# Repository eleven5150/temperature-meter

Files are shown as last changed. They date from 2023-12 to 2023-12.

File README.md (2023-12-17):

# temperature-meter

Устройство визуальной индикации температуры в помещении

# PCB

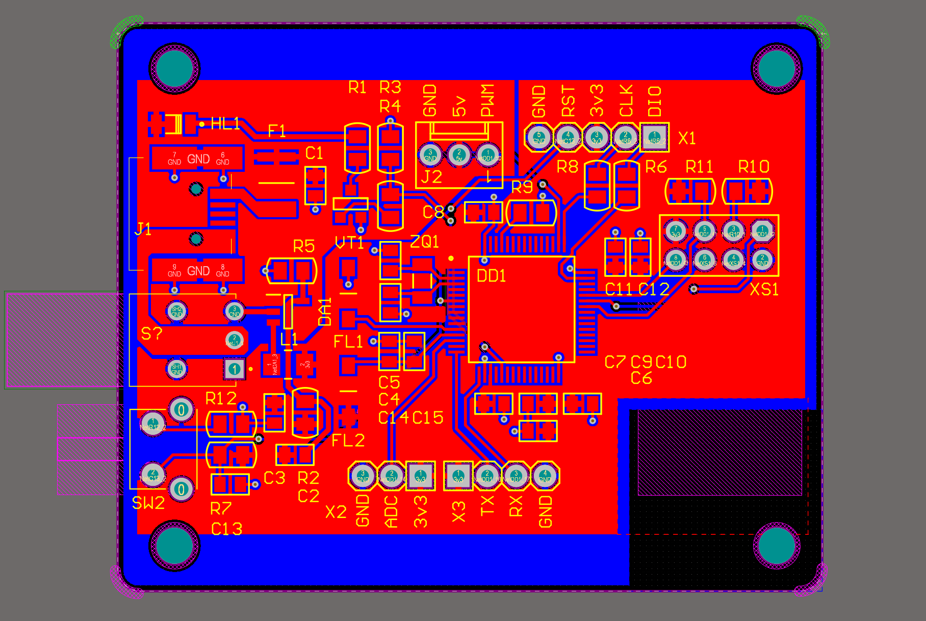
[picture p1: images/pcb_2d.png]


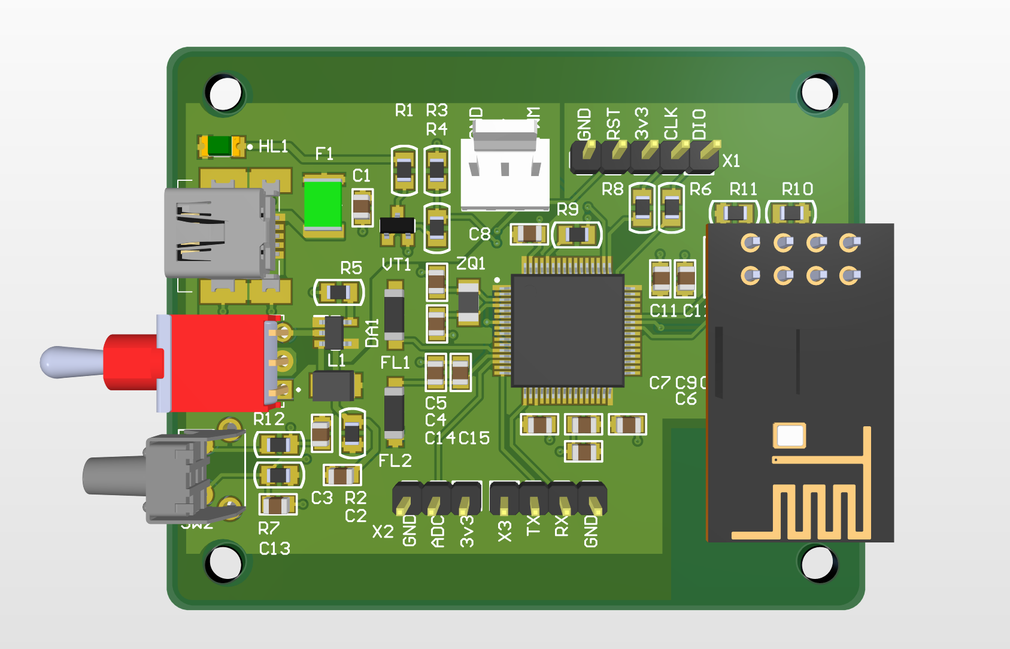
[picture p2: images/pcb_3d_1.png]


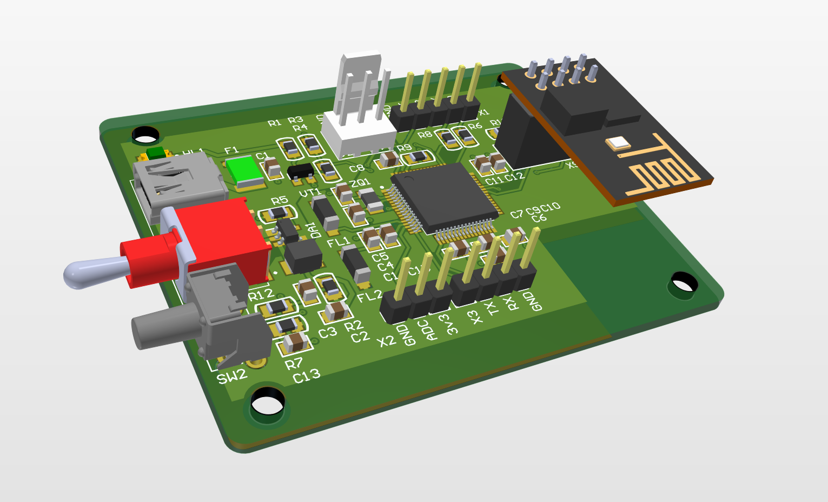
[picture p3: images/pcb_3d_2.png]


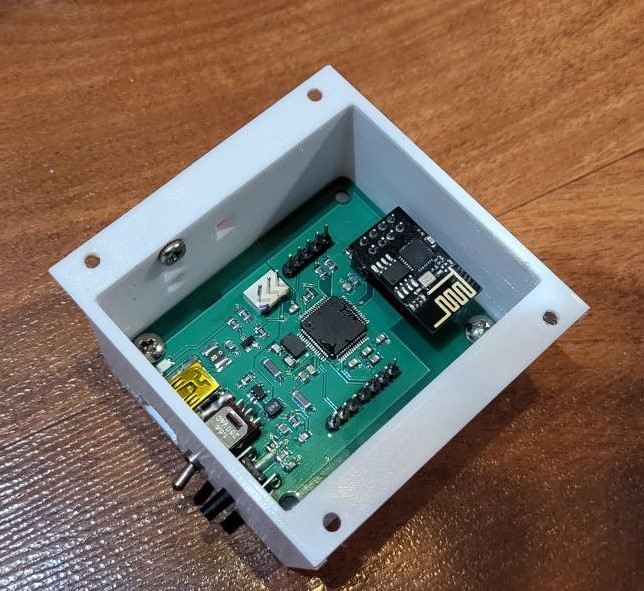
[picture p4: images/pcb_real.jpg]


# Case

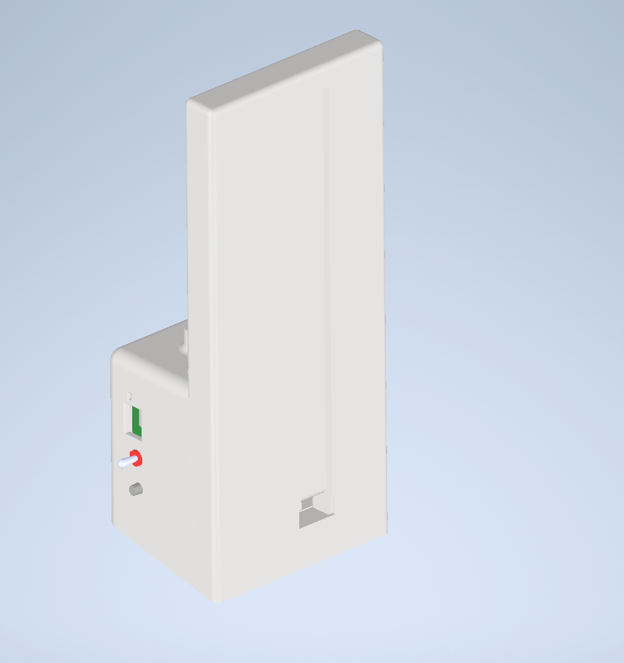
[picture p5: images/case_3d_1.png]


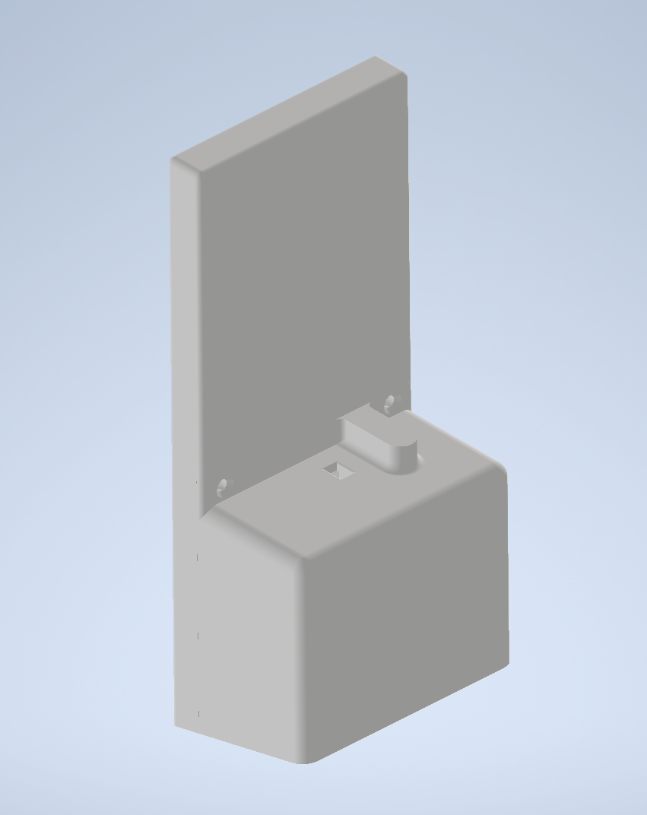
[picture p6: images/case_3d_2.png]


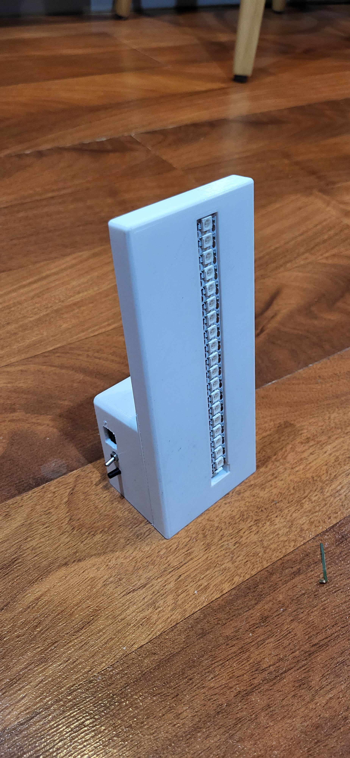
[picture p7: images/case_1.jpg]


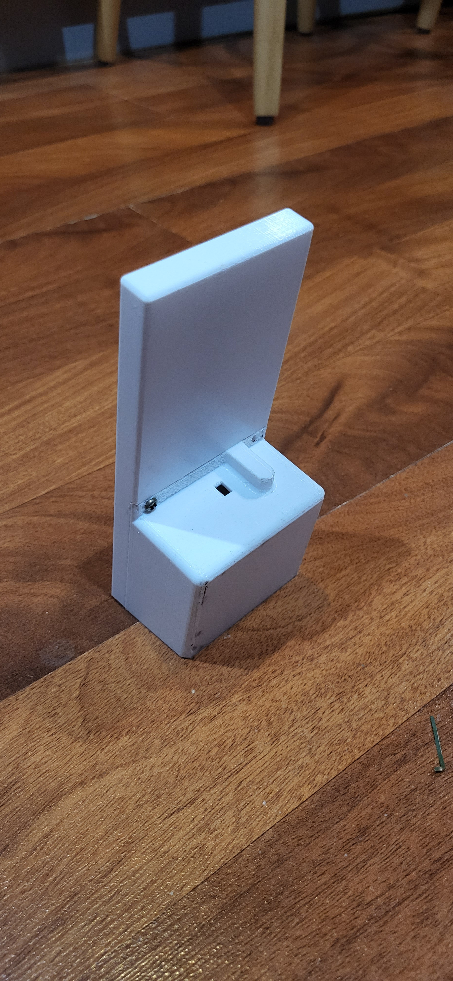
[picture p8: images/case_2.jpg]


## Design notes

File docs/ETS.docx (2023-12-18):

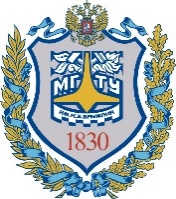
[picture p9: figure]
Gerb-BMSTU_01

| Министерство науки и высшего образования Российской Федерации Федеральное государственное бюджетное образовательное учреждение высшего образования «Московский государственный технический университет имени Н.Э. Баумана (национальный исследовательский университет)» (МГТУ им. Н.Э. Баумана)

ФАКУЛЬТЕТ «ИНФОРМАТИКА, ИСКУССТВЕННЫЙ ИНТЕЛЛЕКТ И СИСТЕМЫ УПРАВЛЕНИЯ» (ИУ)

КАФЕДРА «ПРОЕКТИРОВАНИЕ И ТЕХНОЛОГИЯ ПРОИЗВОДСТВА ЭА» (ИУ4)

РАСШИРЕННОЕ ТЕХНИЧЕСКОЕ ЗАДАНИЕ

на выполнение курсового проекта

на тему: «Устройство визуальной индикации температуры в помещении»

Студент ИУ4-31М _________________ Кутаев К.С.

(Группа) (Подпись, дата)

Руководитель _________________ Орлов А.О.

(Подпись, дата)

Москва, 2023

# 1.1 НАИМЕНОВАНИЕ, НАЗНАЧЕНИЕ И ОБЛАСТЬ ПРИМЕНЕНИЯ.

1.1.1 Наименование разрабатываемого изделия – «Устройство визуальной индикации температуры в помещении».

1.1.2 Изделие предназначено для визуальной индикации температуры в помещении на температурной шкале, а также в цифровом виде на пользовательской веб странице.

1.1.3 Применяется в домашних и офисных помещениях, где необходимо иметь возможность контролировать температуру как визуально, так и иметь ее значение в цифровом виде для передачи каким-либо системам, способным ее регулировать.

1.1.4 «Устройство визуальной индикации температуры в помещении» осуществляет соединение по беспроводной технологии Wi-Fi и является HTTP сервером для подключения к нему клиентских устройств и возможностью обмена данными по протоколу HTTP. На устройстве расположена светодиодная лента, которая осуществляет визуальную индикацию температуры в помещении на температурной шкале градусов Цельсия.

1.2 ОСНОВАНИЕ ДЛЯ РАЗРАБОТКИ.

1.2.1 Настоящее техническое задание разработано в соответствии с заданием на курсовой проект кафедры ИУ4 МГТУ им Н. Э. Баумана.

1.3 ЦЕЛЬ И НАЗНАЧЕНИЕ РАЗРАБОТКИ.

1.3.1 Цель разработки – создание «Устройства визуальной индикации температуры в помещении», для визуальной индикации температуры в помещении на температурной шкале, а также в цифровом виде на пользовательской веб странице.

1.3.2 «Устройство визуальной индикации температуры в помещении» должно иметь питание, достаточное для нормальный работы светодиодной ленты и работать в климатических условиях УХЛ 3.1.

# 1.4 ИСТОЧНИКИ РАЗРАБОТКИ.

1.4.1 Опыт, накопленный студентом в разработке устройств, использующих светодиоды в качестве индикации и опыт работы с АЦП.

1.4.2 Анализ источников информации об аналогах.

# 1.5 ПРИНЦИП ДЕЙСТВИЯ.

1.5.1 Для включения устройства необходимо подключить устройство к сети питания постоянного тока 5В по средствам USB кабеля USB Type-A на Mini-USB Type-B. После подачи питания на «Устройство визуальной индикации температуры в помещении» загорится светодиод, означающий правильную работу устройства.

Функционал режимов индикации и передачи данных по сети регулируются соответствующей версией внутреннего программного обеспечения УВИТП, в зависимости от назначения поставки, загружаемого непосредственно при выполнении заказа.

При передаче на Устройство запроса о получении значения температуры в помещении устройство выдает ответ в виде HTML файла с форматированными данными.

# 1.6 ОБЪЕКТ ОБРАБОТКИ.

1.6.1 Объект обработки – информация о температуре в помещении, где расположено УВИТП.

# 1.7 ТЕХНИЧЕСКИЕ ТРЕБОВАНИЯ.

## 1.7.1 Требования по составу изделия.

1.7.1.1 Устройство визуальной индикации температуры в помещении предназначено для визуальной индикации температуры в помещении на температурной шкале, а также в цифровом виде на пользовательской веб странице.

1.7.1.2 В состав каждого изделия должны входить:

- «Устройство визуальной индикации температуры в помещении», далее по тексту УВИТП, со средствами упаковки, обеспечивающими его транспортирование и хранение;

- принадлежности и эксплуатационная документация, необходимые для выполнения работ по обслуживанию УВИТП в условиях эксплуатации и хранения;

1.7.1.3 Комплект ПО, необходимого для эксплуатации УВИТП:

- тестирование (подготовка к работе);

- копирования данных (перенос данных в персональный компьютер);

- расшифровки данных (получение и передача информации, хранящейся на внутренней flash-памяти).

1.7.1.4 В состав устройства входят:

- МК STM32F103RDT6;

- кварцевый резонатор;

- 74 керамических конденсатора;

- импульсный регулятор питания;

- 61 светодиод;

- предохранитель;

- катушка индуктивности;

- 13 резисторов;

- рычаг переключатель;

- тактовая кнопка;

- транзистор;

- вилка штыревая;

- гнездо контактное.

1.7.1.5 Разрабатываемое устройство должно быть выполнено в виде одноплатной электронной ячейки на двухсторонней печатной плате, заключенной в прямоугольный пластмассовый корпус.

## 1.7.2 Требования по назначению.

1.7.2.1 УВИТП должно обеспечивать прием и передачу информации, хранящейся на внутренней flash-памяти;

1.7.2.2 Изделие должно обеспечивать:

- вывод графической информации о температуре в помещении;

- возможность ввода информации посредством протокола HTTP, с последующей передачей данных по беспроводной технологии Wi-Fi;

1.7.2.4 Погрешность определения значения температуры не должна превышать 1 с;

1.7.2.5 Электрическая прочность и сопротивление изоляции УВИТП – по ГОСТ Р 52931;

1.7.2.6 Напряжение питания – 5 В с погрешностью 0,5 В. Ток для питания УВИТП, обеспечиваемое ресурсом источника питания, - не менее 1 Ампера.

1.7.2.7 УВИТП должно сохранять работоспособность при температуре окружающей среды от -10 °C до 40 °C и относительной влажности воздуха 60% при температуре 25 °C.

1.7.2.8 Устройство должен сохранять работоспособность после его транспортирования и хранения при температуре (от минус 25 °C до 50 °C) в среде без агрессивных примесей (кислот, щелочей и др.).

1.7.2.9 Устройство должен сохранять работоспособность при воздействии на него вибрации на диапазоне частот от 10 до 100 Гц по ГОСТ 28203-89.

1.7.2.10 Устройство должен сохранять работоспособность при воздействии на него ударных нагрузок с ускорением до 10g длительностью до 15 мс и частотой от 40 до 80 1/мин. Вибрация в диапазоне частот от 10 до 100 Гц с ускорением до 1,5 g.

1.7.2.11 Масса Устройства - не более 0,5 кг.

1.7.2.12 Потребляемая мощность устройства не превышает 3 Вт.

1.7.2.13 Максимальный потребляемый ток – 3 А.

1.7.2.14 Технология беспроводной передачи данных – Wi-Fi.

1.7.2.15 Максимальное количество зажигаемых светодиодов на светодиодной ленте – 60 шт.

1.7.2.15 Заданный объём выпуска Nвып= 1000 шт./год.

1.7.2.16 IP адрес устройства выдается с использованием протокола DHCP при подключении к сети.

## 1.7.3 Требования к надежности.

1.7.3.1 Установленная вероятность безотказной работы УВИТП в течение наработки не менее 5000 часов должна быть не менее 0,95.

1.7.3.2 Средний срок службы УВИТП не менее 1,5 лет. Установленный срок службы - 1 год.

## 1.7.4 Требования к уровню унификации и стандартизации.

1.7.4.1 Требования к уровню унификации и стандартизации не предъявляются.

## 1.7.5 Требования безопасности и требования по охране природы.

1.7.5.1 УВИТП должен быть безопасными при использовании его пользователем, прочитавшим правилам эксплуатации устройства.

1.7.5.2 Блок питания и его компоненты должны быть правильно утилизированы.

1.7.5.3 В эксплуатационной документации на Устройство должны быть ссылки на общие требования безопасности в соответствии со следующими документами:

- ГОСТ 12.3.019 Испытания и измерения электрические. Общие требования безопасности;

- ГОСТ 12.2.003 Оборудование производственное. Общие требования безопасности;

- ГОСТ 12.3.020 Процессы перемещения грузов на предприятиях. Общие требования безопасности;

- ГОСТ 12.2.007.0 Изделия электротехнические. Общие требования безопасности;

- ГОСТ 12.1.004 Пожарная безопасность. Общие требования;

- ГОСТ 12.3.002 Процессы производственные. Общие требования безопасности;

1.7.5.4 Требования по охране природы не предъявляются, так как при изготовлении, эксплуатации, транспортировании, хранении, утилизации УВИТП отсутствуют вредные воздействия на элементы окружающей среды.

## 1.7.6 Требования к составным частям, сырью и исходным материалам.

## 1.7.6.1 Покупные изделия и материалы применяются без ограничений.

## 1.7.7 Условия эксплуатации, требования к техническому обслуживанию и ремонту.

1.7.7.1 УВИТП должно быть выполнено для климатической зоны УХЛ 3.1 по ГОСТ 15150.

1.7.7.2 УВИТП должно сохранять работоспособность при температуре среды от -10 °C до 40 °C и относительной влажности воздуха 60% при температуре 25 °C.

1.7.7.3 УВИТП должно сохранять работоспособность после его транспортирования и хранения при температуре от минус 25 °C до 50 °C в среде без агрессивных примесей.

1.7.7.4 Техническое обслуживание УВИТП должно обеспечиваться при проведении работ по их подготовке к обследованию объектов контроля, работ после проведения контроля и работ по подготовке к хранению.

1.7.7.5 Для увеличения достоверности информации, получаемой с установленных устройств ввода и вывода, допускается проведение периодической проверки и калибровки.

## 1.7.8 Требования к маркировке и упаковке.

1.7.8.1 Требования к маркировке не предъявляются.

## 1.7.9 Требования к транспортированию и хранению.

1.7.9.1 УВИТП должно выдерживать транспортирование в пассажирских салонах всех видов транспорта без ограничения расстояния перевозки.

# 1.8 ПОРЯДОК КОНТРОЛЯ И ПРИЕМКИ

1.8.1 Для приемки представляется один опытный образец платы печатной УВИТП, комплект эксплуатационных документов, комплект программного обеспечения, программа и методика приемных испытаний, согласованная в установленном порядке.

1.8.2 Конструкторская и технологическая документация должна быть разработана в соответствии с требованиями ГОСТ ЕСКД.

1.8.3 В комплекты эксплуатационных документов должны быть включены следующие документы:

– схема электрическая структурная УВИТП (Э1),

– схема электрическая принципиальная УВИТП (Э3),

– схема электрическая соединений УВИТП (Э4),

– перечень элементов электронной ячейки УВИТП (ПЭ),

– чертеж печатной платы УВИТП(ПП),

– сборочный чертеж электронной ячейки УВИТП(СБ),

– спецификация электронной ячейки УВИТП(СП),

– чертежи основания и крышки корпуса УВИТП,

– сборочный чертёж УВИТП,

– спецификация УВИТП(СП),

– алгоритм работы УВИТП,

– расчётно-пояснительная записка.

1.8.4 Приемные испытания УВИТП проводятся на образцах с искусственными или естественными дефектами, предоставляемыми заказчиком.

1.8.5 По результатам проведения испытаний, при необходимости проводится корректировка конструкторской документации.

1.8.6 Отдельные требования настоящего технического задания могут изменяться и дополняться по согласованию сторон в установленном порядке.

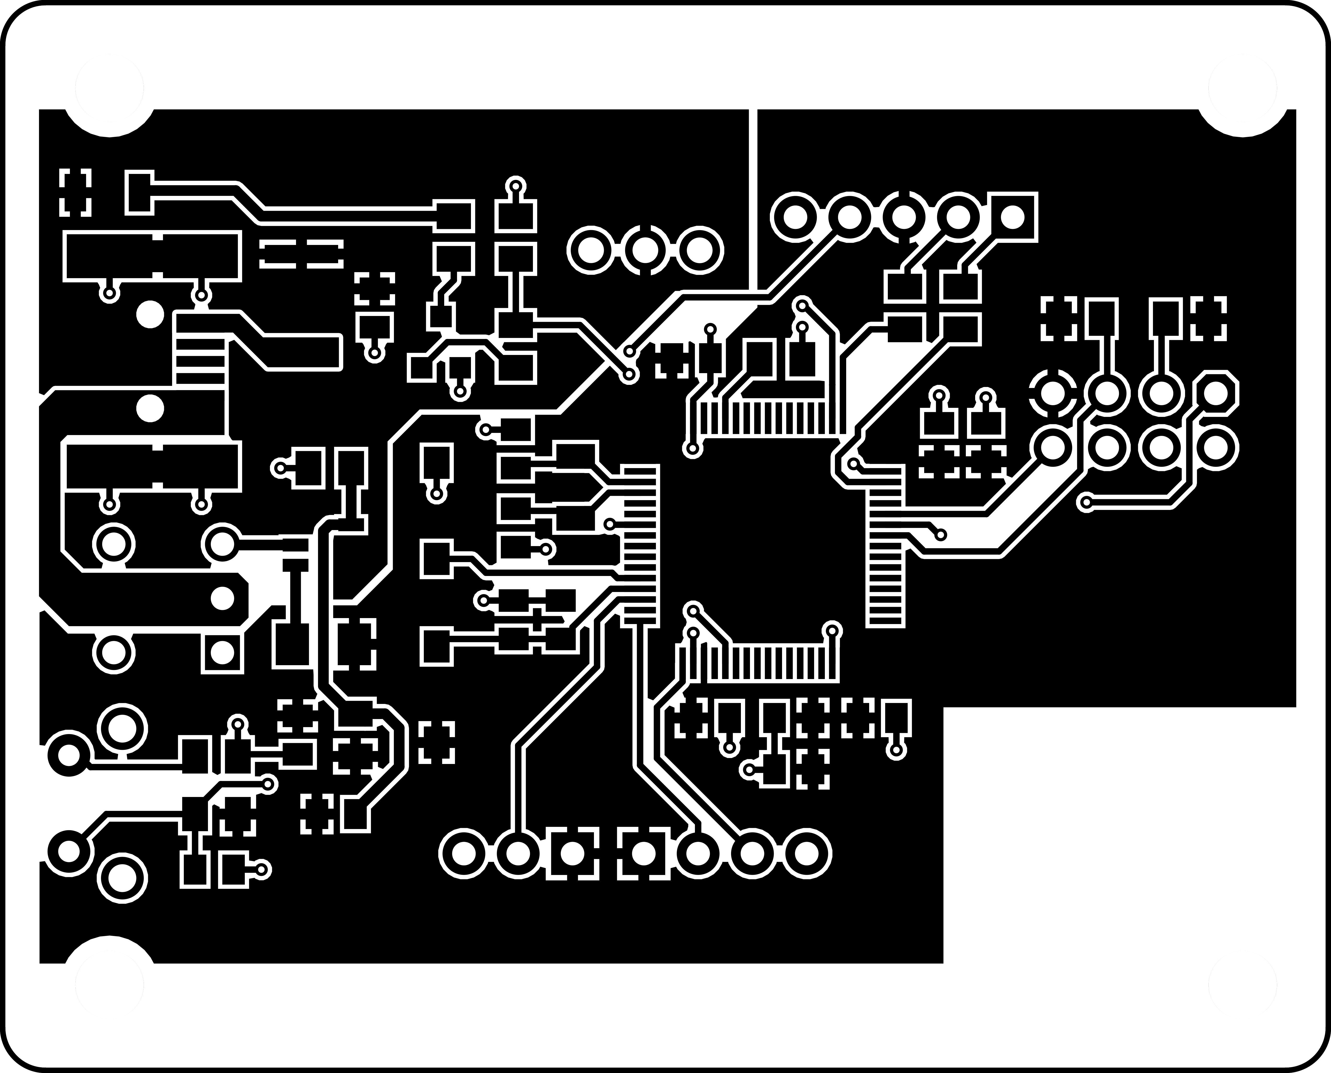
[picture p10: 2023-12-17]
docs/drawings/cell/src/pcb_src/top.png

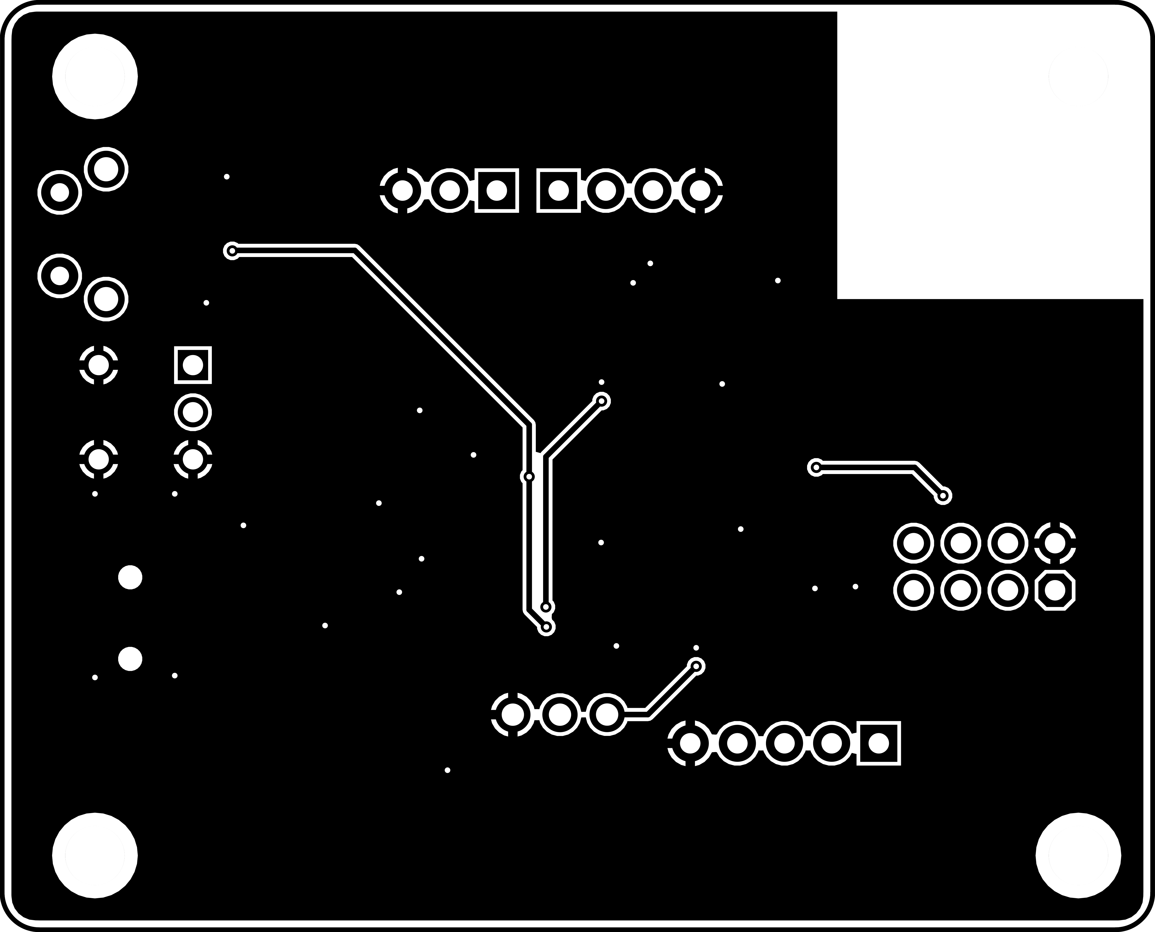
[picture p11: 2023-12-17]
docs/drawings/cell/src/pcb_src/bot.png

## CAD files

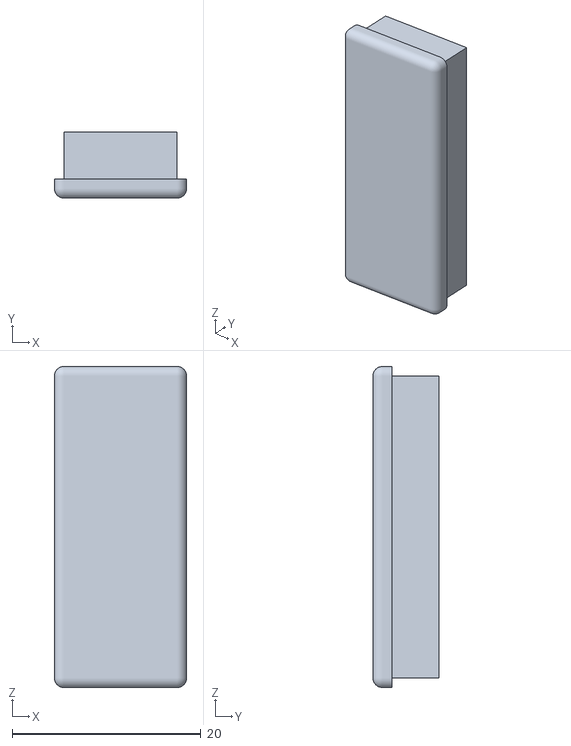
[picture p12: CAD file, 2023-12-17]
case/pcb/ST_FLASH.stl
14.0 x 7.00 x 34.0

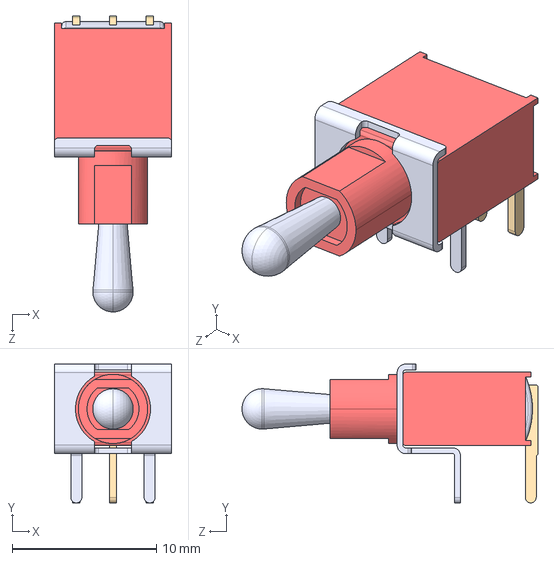
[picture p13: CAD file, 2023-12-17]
pcb/2AS1T2A1M6RES--3DModel-STEP-56544.STEP
8.13 x 9.62 x 20.5 mm

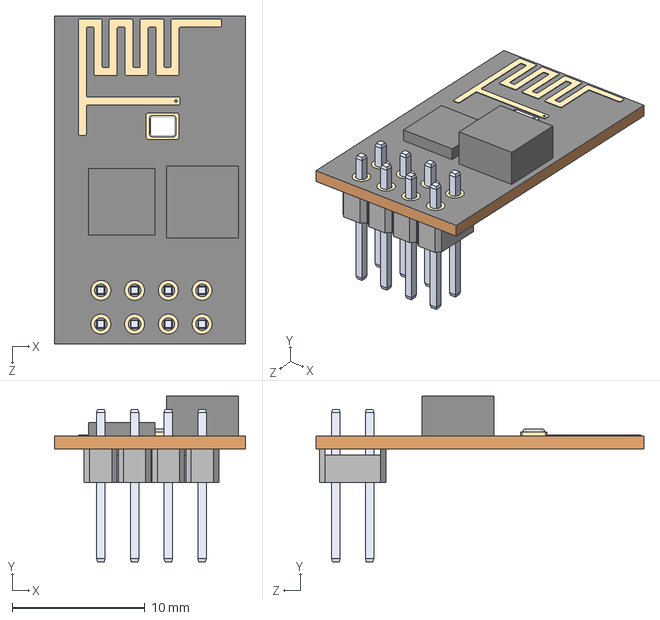
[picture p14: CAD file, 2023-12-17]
pcb/ESP-01.STEP
14.4 x 12.5 x 24.7 mm

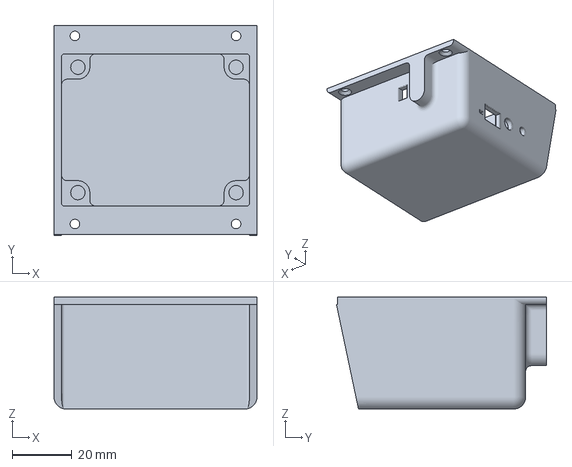
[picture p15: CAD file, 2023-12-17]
pcb/CE3PRO_Top.3mf
68.0 x 70.4 x 37.5 mm

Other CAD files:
docs/drawings/device/src/Assembly.dwg
docs/drawings/cell/src/Assembly.dwg
docs/drawings/cell/src/E3.dwg
docs/drawings/device/src/Case Cap.dwg
pcb/export_step/pcbPCB1_A.dwg
docs/drawings/cell/src/E4.dwg
docs/drawings/device/src/Case Base.dwg
pcb/export_step/pcbPCB1_I.dwg
docs/drawings/cell/src/BOM.dwg
docs/drawings/cell/src/E1.dwg
docs/drawings/device/src/Specs.dwg
docs/drawings/cell/src/PCB.dwg
docs/drawings/device/src/Research Result.dwg
docs/drawings/device/src/Algorithm.dwg
case/Base.ipt
case/Cap.ipt
case/Case-ASMB.iam
case/Temp_Module.ipt
case/pcb/7243460688.ipt
case/pcb/7243461008.iam
case/pcb/7243461088.ipt
case/pcb/7243462128.ipt
case/pcb/7243474768.iam
case/pcb/7403978528.iam
case/pcb/Board.iam
case/pcb/Body_1.ipt
case/pcb/Body_2.ipt
case/pcb/C1.iam
case/pcb/C10.iam
case/pcb/C11.iam
case/pcb/C12.iam
case/pcb/C13.iam
case/pcb/C14.iam
case/pcb/C15.iam
case/pcb/C2.iam
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

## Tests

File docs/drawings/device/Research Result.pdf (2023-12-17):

Пакет с цветовым кодом для светодиодной ленты . Способ передачи - ШИМ

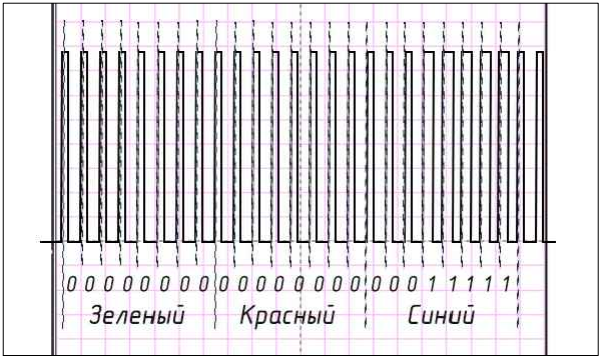
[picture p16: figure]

Теоретический график

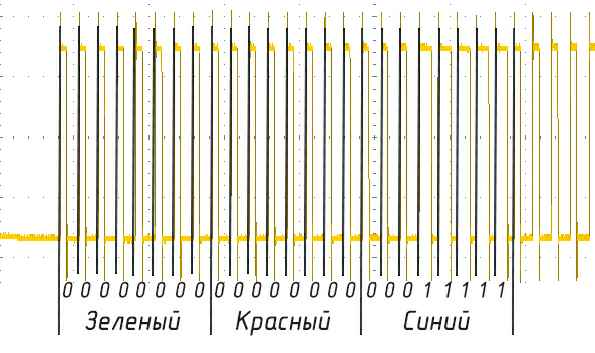
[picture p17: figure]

Практический график

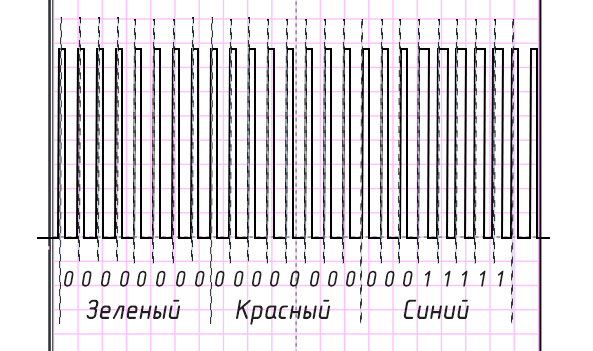
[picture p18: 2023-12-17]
docs/drawings/device/src/research_result_pictures/ledstripMod.jpg

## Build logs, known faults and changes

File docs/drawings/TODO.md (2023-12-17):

# Cell
- [x] E1
- [x] E3
- [x] BOM
- [x] E4
- [x] PCB
- [x] Assembly
- [x] Specs

# Device

- [x] Algorithm
- [x] Case Base
- [x] Case Cap
- [x] Case Assembly 
- [x] Device Specs
- [x] Research stand
- [x] Research result

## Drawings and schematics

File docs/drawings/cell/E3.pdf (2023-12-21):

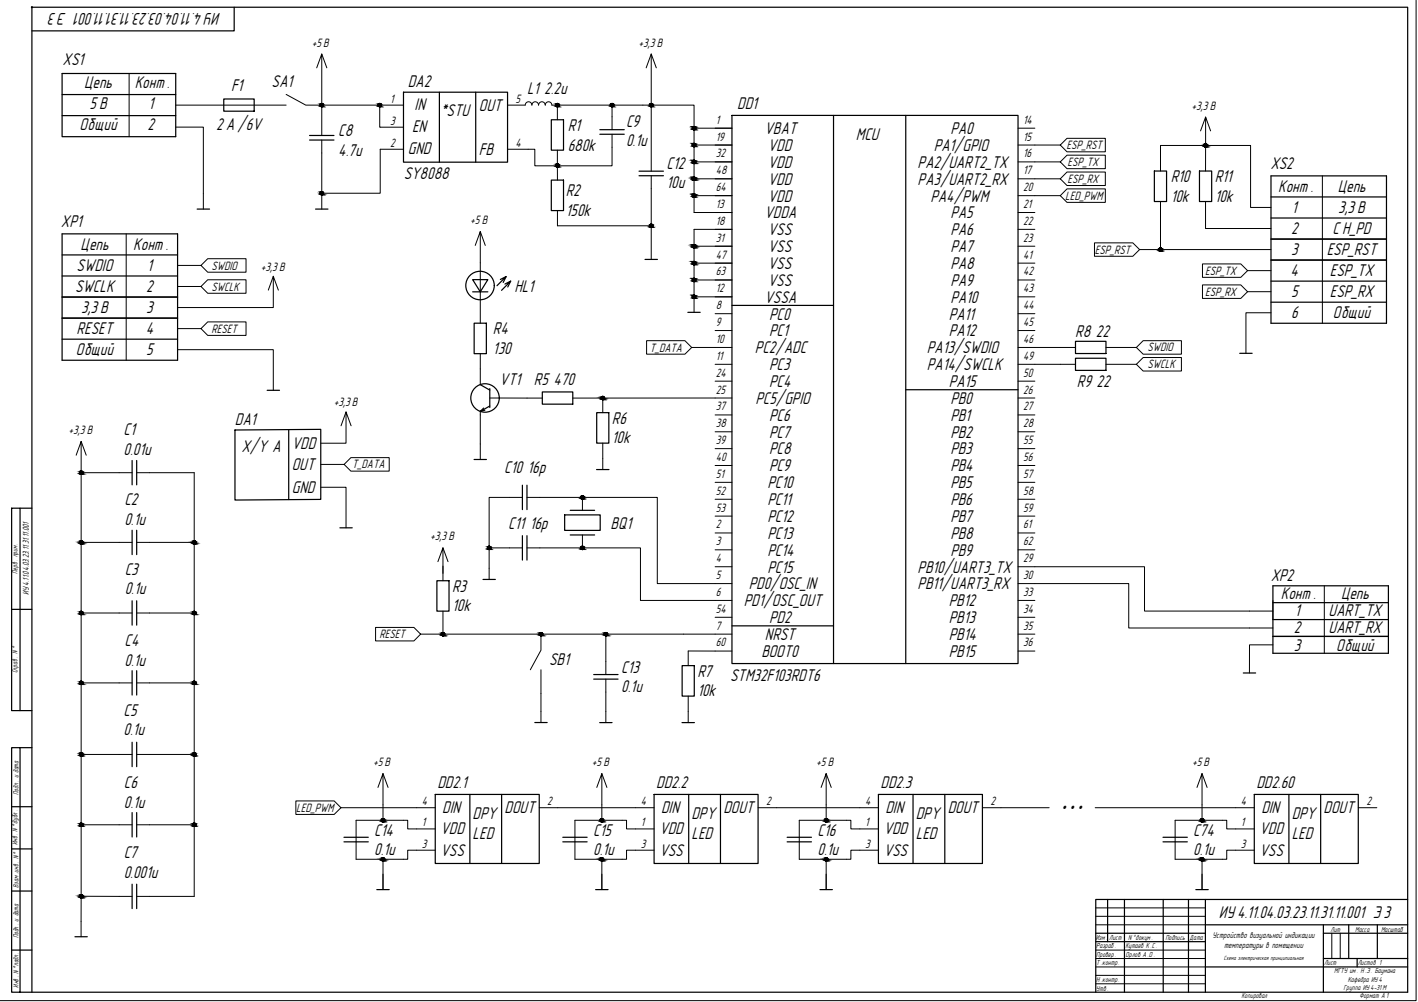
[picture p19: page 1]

2 | С H_PD
3 | ESP_RST
4 | ESP_TX

31 | 23
47 | 41
63 | 42

Цепь | Конт . SWDIO 1

SWCLK | 2

RESET | 4
Общий | 5

Провер . Т .контр . Разраб . Перв . прим . Справ . N ° Подп . и дата Инв . N °дубл . Подп . и дата Взам .инв . N °

5 | | 30
6 | | 33

Конт . | Цепь
1 | UART_TX
2 | UART_RX
3 | Общий

Устройство визуальной индикации температуры в помещении Схема электрическая принципиальная | Лит | Масса | Масштаб

Изм . Лист | N °докум . | Подпись | Дата

Утв . Н .контр . Инв . N °подп .

Лист | Листов 1

Кафедра ИУ 4 Группа ИУ 4-31 М

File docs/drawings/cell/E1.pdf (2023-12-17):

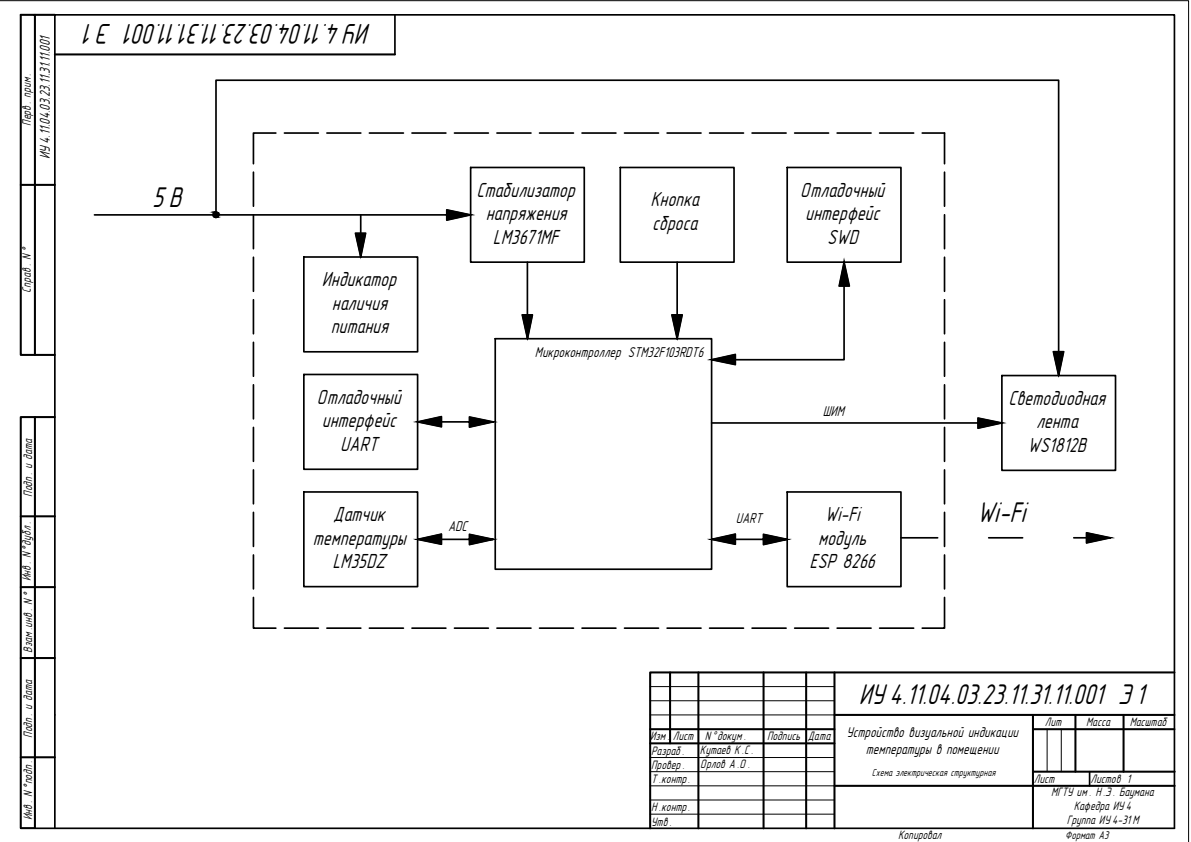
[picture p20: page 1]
Копировал; Формат А3; Кутаев К .С . Орлов А .О .; МГТУ им . Н .Э . Баумана; Схема электрическая структурная Подп . и дата Инв . N °дубл . Подп . и дата Взам .инв . N ° Инв . N °подп . Перв . прим . Справ . N °; Микроконтроллер STM32F103RDT6; ESP 8266; UART ADC

Устройство визуальной индикации температуры в помещении | Лит | Масса | Масштаб

Изм . Лист | N °докум . | Подпись | Дата
Провер . Т .контр . Разраб .

Лист | Листов 1

Утв . Н .контр .

Кафедра ИУ 4 Группа ИУ 4-31 М

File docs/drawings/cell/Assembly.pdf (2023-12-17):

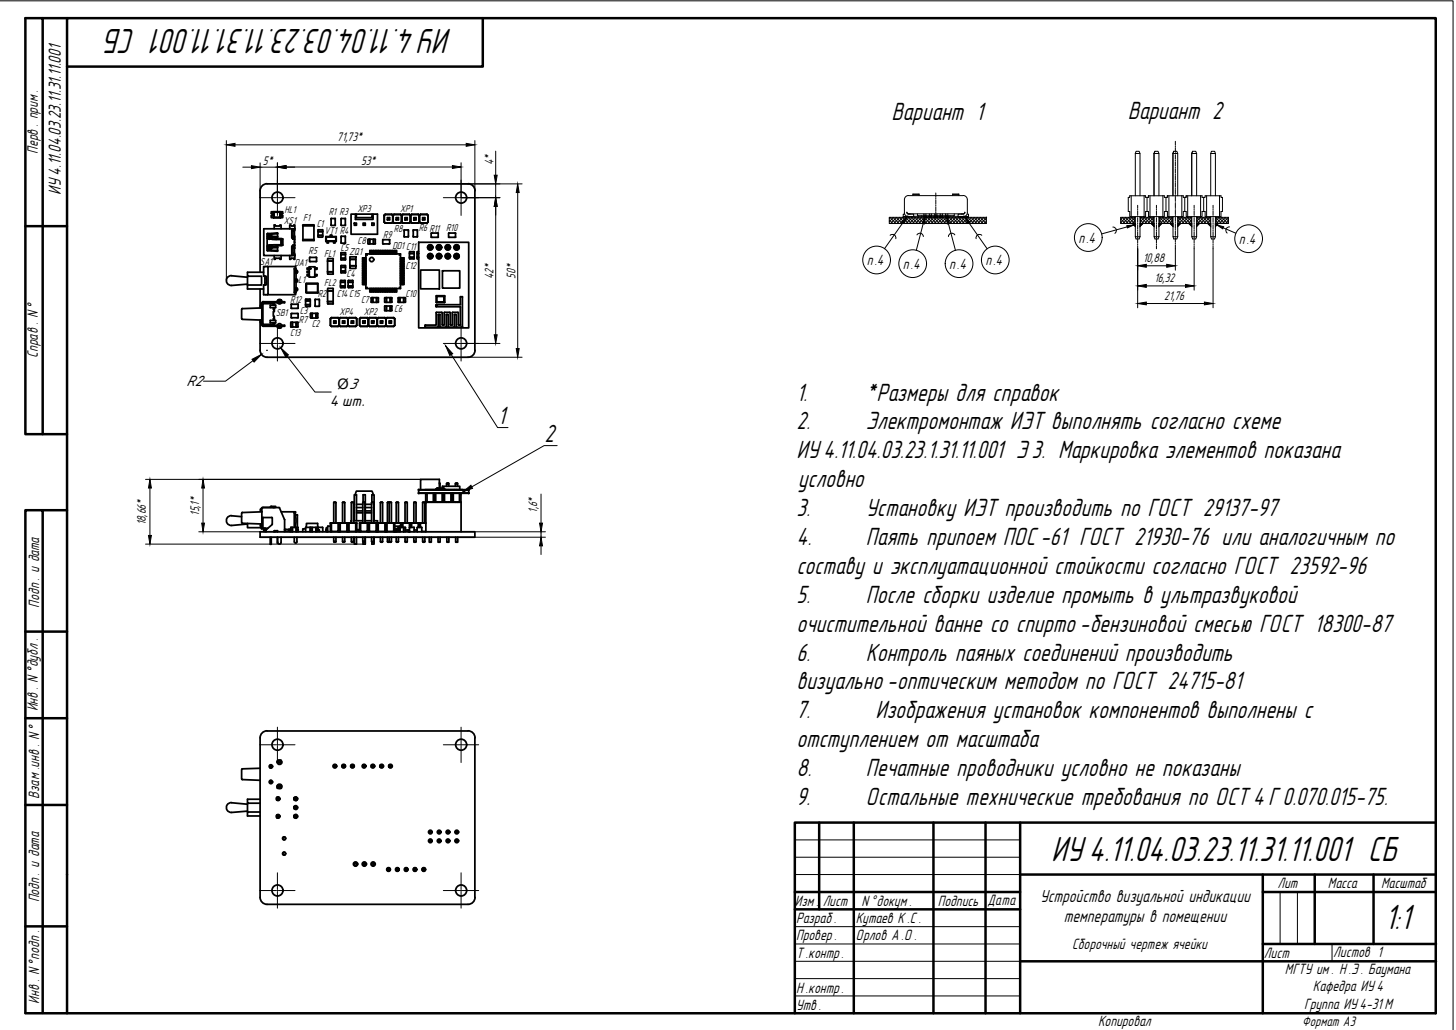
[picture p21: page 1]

1. *Размеры для справок
2. Электромонтаж ИЭТ выполнять согласно схеме
ИУ 4.11.04.03.23.1.31.11.001 Э 3. Маркировка элементов показана
условно
3. Установку ИЭТ производить по ГОСТ 29137-97
4. Паять припоем ПОС -61 ГОСТ 21930-76 или аналогичным по
составу и эксплуатационной стойкости согласно ГОСТ 23592-96
5. После сборки изделие промыть в ультразвуковой
очистительной ванне со спирто -бензиновой смесью ГОСТ 18300-87
6. Контроль паяных соединений производить
визуально -оптическим методом по ГОСТ 24715-81
7. Изображения установок компонентов выполнены с
отступлением от масштаба
8. Печатные проводники условно не показаны

Подпись | Дата | ИУ 4.11.04.03.23.11.31.11.001 СБ N °докум .

Устройство визуальной индикации | Лит | Масса | Масштаб

Изм . Лист | | | | | 1:1
Провер . Т .контр . Разраб .

Лист | Листов 1

Утв . Н .контр .

Кафедра ИУ 4 Группа ИУ 4-31 М

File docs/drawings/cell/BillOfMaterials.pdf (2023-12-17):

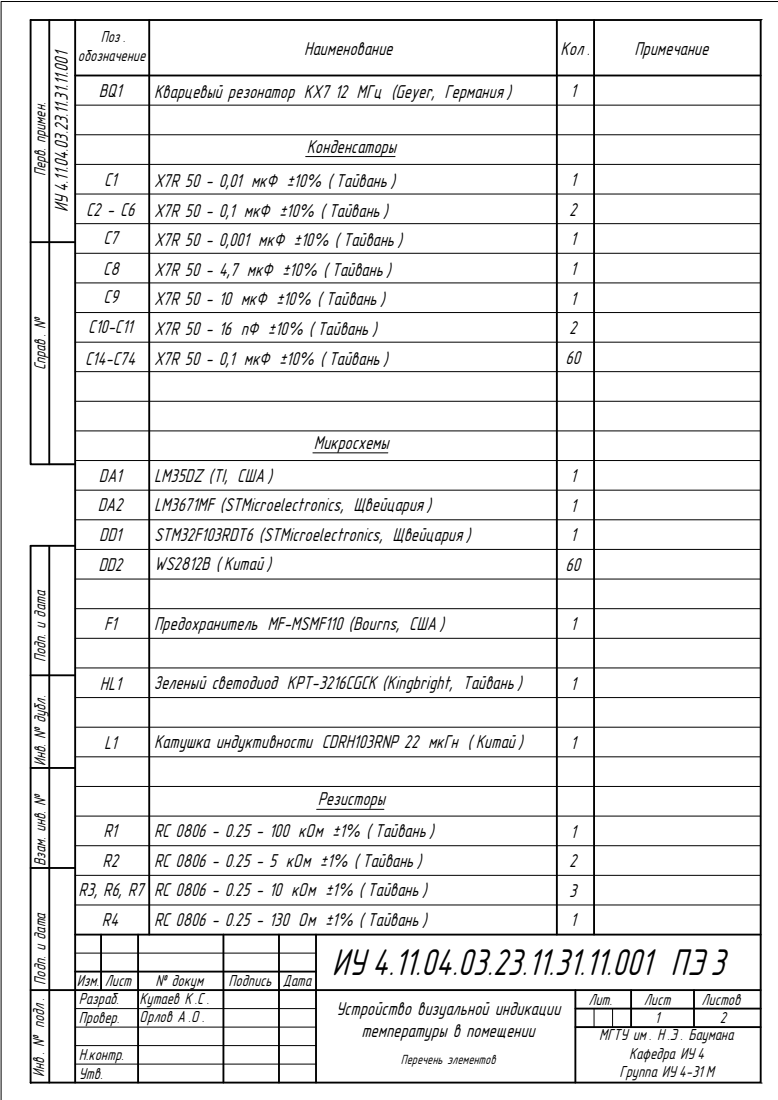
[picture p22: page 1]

Перв. примен. Взам. инв. № Подп. и дата

Инв. № дубл. Подп. и дата

Зеленый светодиод KPT-3216CGCK (Kingbright, Тайвань )

Разраб. | Кутаев К .С . Орлов А .О .
Провер.

Перв. примен. Справ . №

Поз . обозначение | Наименование | Кол . | Примечание
R5 | | 1
R8-R9 | RC 0806 - 0.25 - 22 Ом ±1% ( Тайвань ) | 2
R10-R11 | RC 0806 - 0.25 - 10 кОм ±1% ( Тайвань ) | 2
Изм. Лист | № докум | Подпись | Дата

Лист

## ИУ 4.11.04.03.23.11.31.11.001 ПЭ 3

| Переключатели
SA1 | 2AS1T2A1M6RES (KLS Electronic, Китай ) | 1
SB1 | SDTM-630-N (KLS Electronic, Китай ) | 1
VT1 | Транзистор BC182LB (Fairchild, США )
| Разъемы
XP1 | PBS-5 (Connfly, Китай ) | 1
XP2 | PBS-3 (Connfly, Китай ) | 1
XS1 | MicroUSB Type-B 47346-0001 (Molex, Китай ) | 1
XS2 | PLS-6 (Connfly, Китай ) | 2

1

2 Взам. инв. № Подп. и дата Инв. № дубл. Подп. и дата Инв . № подл . | ИУ 4.11.04.03.23.11.31.11.001 | RC 0806 - 0.25 - 470 Ом ±1% ( Тайвань )

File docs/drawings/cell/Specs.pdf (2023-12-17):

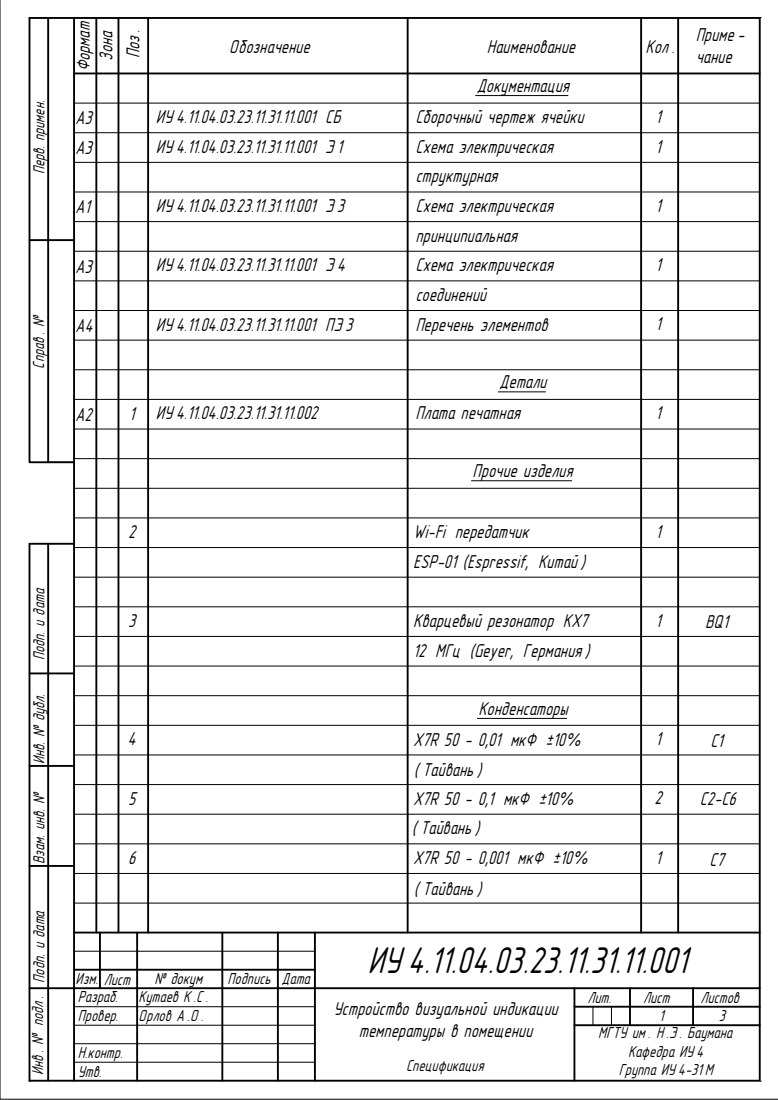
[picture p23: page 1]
Лист; № докум; Подпись; Дата; Наименование; Кол .; Приме -; Сборочный чертеж ячейки; Схема электрическая; Перечень элементов; Плата печатная; Прочие изделия; X7R 50 - 0,01 мкФ ±10%; X7R 50 - 0,1 мкФ ±10%; ( Тайвань ); Wi-Fi передатчик; X7R 50 - 0,001 мкФ ±10%

Обозначение Поз . Зона Формат

Перв. примен. Взам. инв. № Подп. и дата

Листов Инв . № подл . Справ . №

ESP-01 (Espressif, Китай )

Инв. № дубл. Подп. и дата

Кварцевый резонатор KX7
12 МГц (Geyer, Германия )

Разраб. | Кутаев К .С . Орлов А .О .
Провер.

Устройство визуальной индикации
температуры в помещении

МГТУ им . Н .Э . Баумана
Кафедра ИУ 4
Группа ИУ 4-31 М

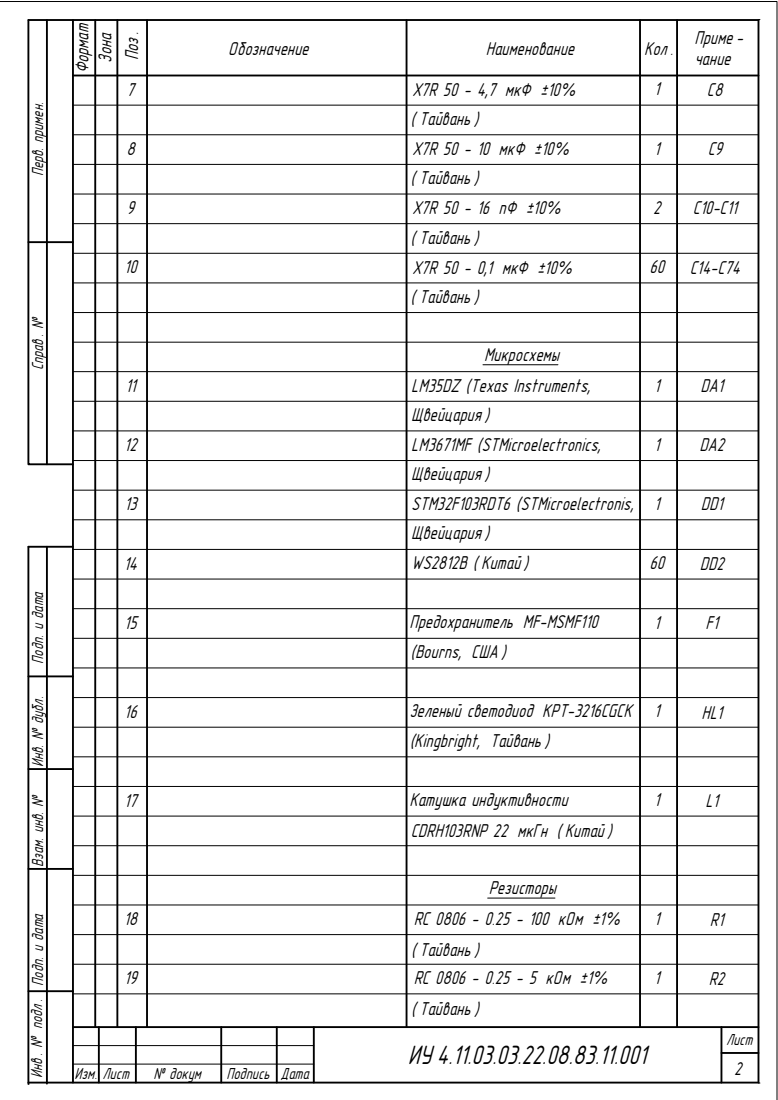
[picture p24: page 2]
Изм. Лист; № докум; Подпись; Дата

7 | X7R 50 - 4,7 мкФ ±10% | 1 | C8

Перв. примен. Справ . №

( Тайвань )

8 | X7R 50 - 10 мкФ ±10% | 1 | C9

10 | X7R 50 - 0,1 мкФ ±10% | 60 | C14-C74

Микросхемы

11 | LM35DZ (Texas Instruments, | 1 | DA1

Щвейцария )

12 | LM3671MF (STMicroelectronics, | 1 | DA2

13 | STM32F103RDT6 (STMicroelectronis, | 1 | DD1

14 | WS2812B ( Китай ) | 60 | DD2

ИУ 4.11.03.03.22.08.83.11.001 (Kingbright, Тайвань ) | | 2 Взам. инв. № Подп. и дата Инв. № дубл. Подп. и дата Инв . № подл .

15 | Предохранитель MF-MSMF110 | 1 | F1

(Bourns, США )

16 | Зеленый светодиод KPT-3216CGCK | 1 | HL1

17 | Катушка индуктивности | 1 | L1

CDRH103RNP 22 мкГн ( Китай )

Резисторы

18 | RC 0806 - 0.25 - 100 кОм ±1% | 1 | R1

19 | RC 0806 - 0.25 - 5 кОм ±1% | 1 | R2

Лист

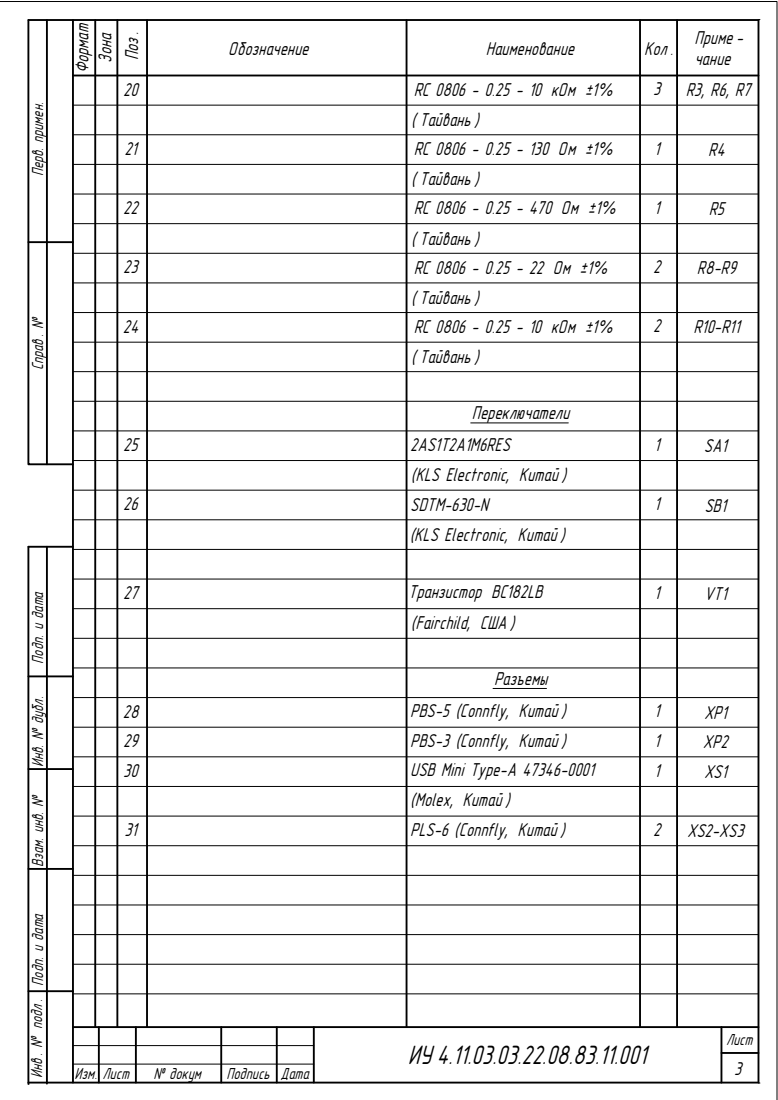
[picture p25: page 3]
Изм. Лист; № докум; Подпись; Дата

20 | RC 0806 - 0.25 - 10 кОм ±1% | 3 | R3, R6, R7

Перв. примен. Справ . №

( Тайвань )

24 | RC 0806 - 0.25 - 10 кОм ±1% | 2 | R10-R11

Переключатели

25 | 2AS1T2A1M6RES | 1 | SA1

(KLS Electronic, Китай )

26 | SDTM-630-N | 1 | SB1

29 | ИУ 4.11.03.03.22.08.83.11.001 PBS-3 (Connfly, Китай ) | 1 | 3 Взам. инв. № Подп. и дата Инв. № дубл. Подп. и дата Инв . № подл . XP2

27 | Транзистор BC182LB | 1 | VT1

(Fairchild, США )

Разъемы

28 | PBS-5 (Connfly, Китай ) | 1 | XP1

30 | USB Mini Type-A 47346-0001 | 1 | XS1

(Molex, Китай )

31 | PLS-6 (Connfly, Китай ) | 2 | XS2-XS3

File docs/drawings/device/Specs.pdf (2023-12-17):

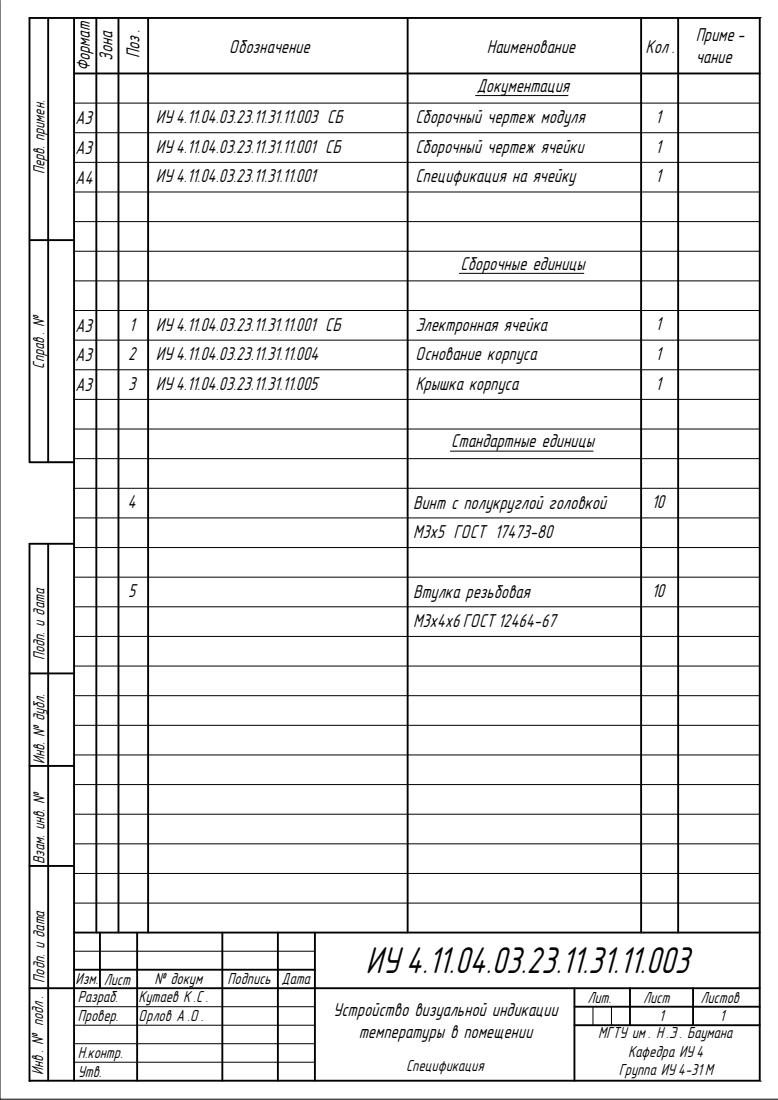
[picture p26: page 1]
Лист; № докум; Подпись; Дата; Наименование; Кол .; Приме -; Сборочный чертеж модуля; Спецификация на ячейку; Сборочные единицы; Электронная ячейка; Втулка резьбовая; M3x4x6 ГОСТ 12464-67; Основание корпуса; Крышка корпуса; Стандартные единицы

Обозначение Поз . Зона Формат

Перв. примен. Взам. инв. № Подп. и дата

Сборочный чертеж ячейки

Листов Инв . № подл . Справ . №

Винт с полукруглой головкой
M3x5 ГОСТ 17473-80

Инв. № дубл. Подп. и дата

Разраб. | Кутаев К .С . Орлов А .О .
Провер.

Устройство визуальной индикации
температуры в помещении

МГТУ им . Н .Э . Баумана
Кафедра ИУ 4
Группа ИУ 4-31 М

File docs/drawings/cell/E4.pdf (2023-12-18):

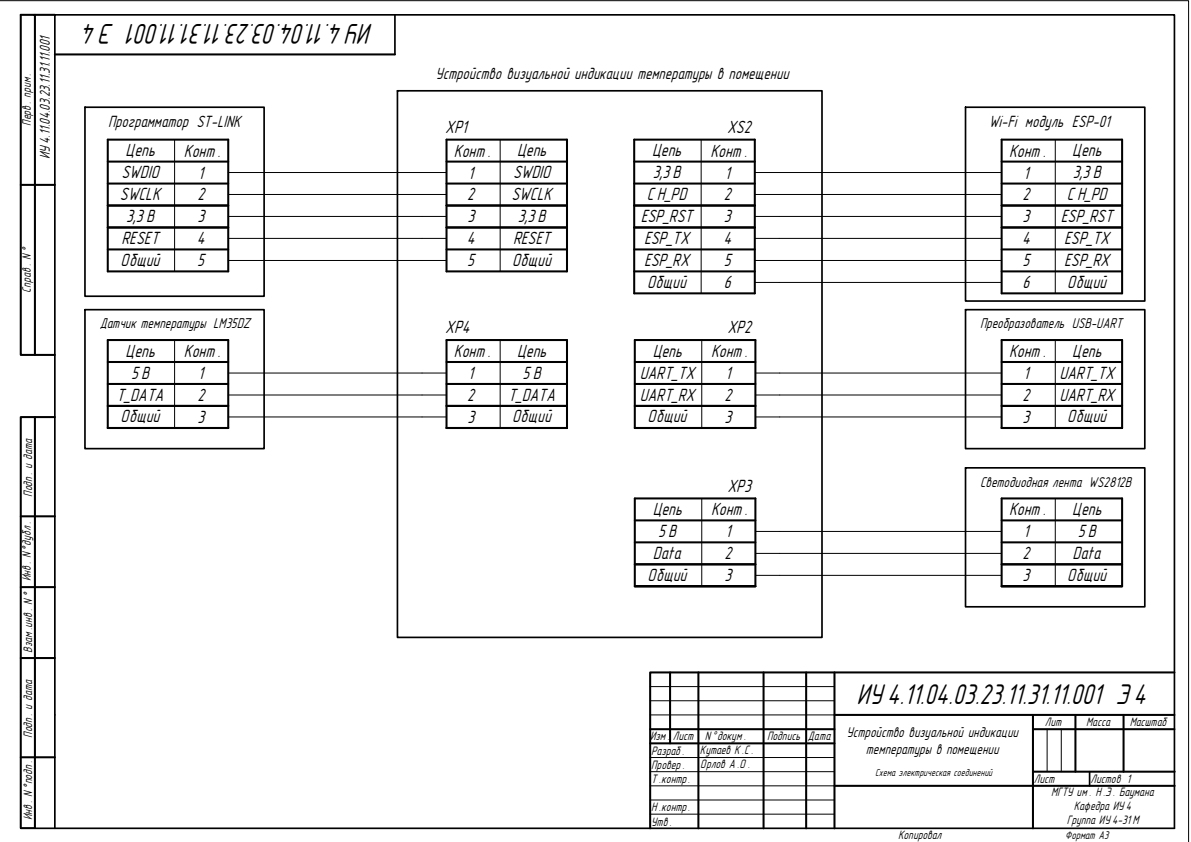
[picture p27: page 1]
Копировал; Формат А3; Кутаев К .С . Орлов А .О .; МГТУ им . Н .Э . Баумана; Схема электрическая соединений Подп . и дата Инв . N °дубл . Подп . и дата Взам .инв . N ° Инв . N °подп . Перв . прим . Справ . N °; Устройство визуальной индикации температуры в помещении; Конт . 1; Программатор ST-LINK; Датчик температуры LM35DZ; Светодиодная лента WS2812B

Wi-Fi модуль ESP-01
Конт . 1

Преобразователь USB-UART

Устройство визуальной индикации температуры в помещении | Лит | Масса | Масштаб

Изм . Лист | N °докум . | Подпись | Дата
Провер . Т .контр . Разраб .

Лист | Листов 1

Утв . Н .контр .

Кафедра ИУ 4 Группа ИУ 4-31 М

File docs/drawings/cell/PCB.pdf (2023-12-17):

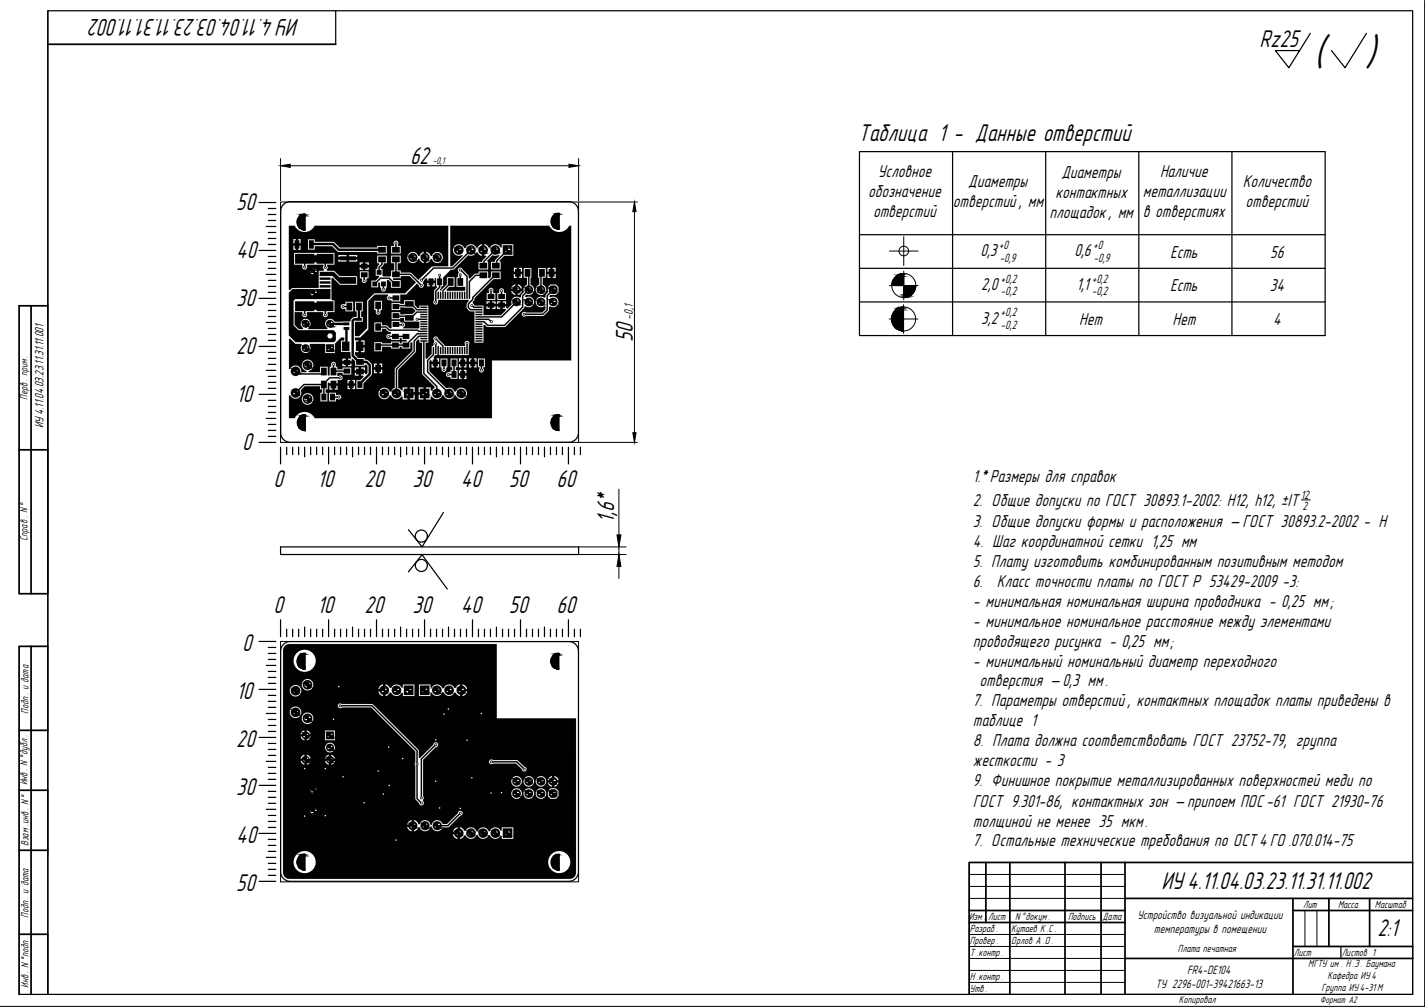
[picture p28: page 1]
Кутаев К .С . Орлов А .О .; МГТУ им . Н .Э . Баумана; Копировал; Формат А2

Таблица 1 - Данные отверстий

Условное обозначение отверстий | Диаметры отверстий , мм | Диаметры контактных площадок , мм | Наличие металлизации в отверстиях | Количество отверстий

+0 0,3 -0,9 | +0 0,6 -0,9 | Есть | 56

+0,2 2,0 -0,2 | +0,2 1,1 -0,2 | Есть | 34

+0,2 3,2 -0,2 | Нет | Нет | 4

1.* Размеры для справок
2. Общие допуски по ГОСТ 30893.1-2002: H12, h12, ±IT
3. Общие допуски формы и расположения – ГОСТ 30893.2-2002 - Н
4. Шаг координатной сетки 1,25 мм
5. Плату изготовить комбинированным позитивным методом
6. Класс точности платы по ГОСТ Р 53429-2009 -3:
- минимальная номинальная ширина проводника - 0,25 мм ;
- минимальное номинальное расстояние между элементами
проводящего рисунка - 0,25 мм ;
- минимальный номинальный диаметр переходного
отверстия – 0,3 мм . 7. Параметры отверстий , контактных площадок платы приведены в

таблице 1
8. Плата должна соответствовать ГОСТ 23752-79, группа
жесткости - 3
9. Финишное покрытие металлизированных поверхностей меди по
ГОСТ 9.301-86, контактных зон – припоем ПОС -61 ГОСТ 21930-76
толщиной не менее 35 мкм . 7. Остальные технические требования по ОСТ 4 ГО .070.014-75

Подпись | Дата | ИУ 4.11.04.03.23.11.31.11.002 N °докум .

Лит | Масса | Масштаб

Изм . Лист | Устройство визуальной индикации температуры в помещении Плата печатная | | | | 2:1
Провер . Т .контр . Разраб .

Лист | Листов 1

FR4-DE104 | Кафедра ИУ 4 Группа ИУ 4-31 М

Утв . Н .контр .

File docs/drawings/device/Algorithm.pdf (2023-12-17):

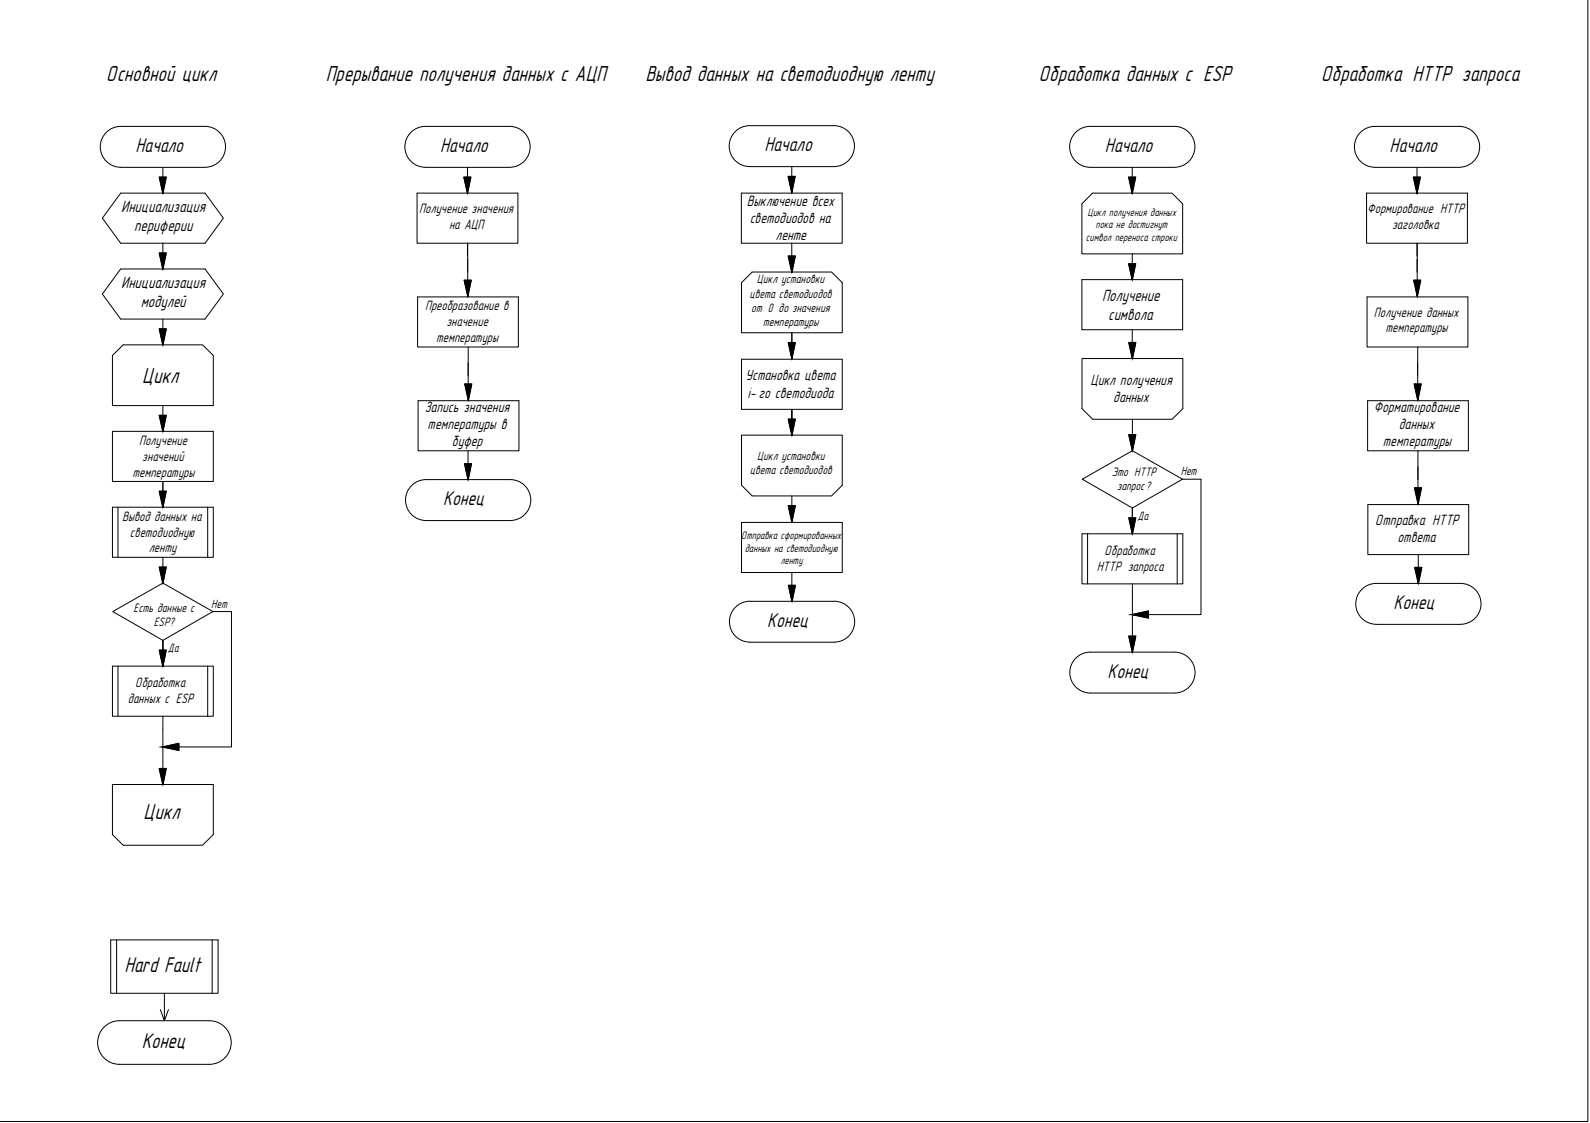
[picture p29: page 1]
Hard Fault; Получение значения на АЦП; Преобразование в; Выключение всех светодиодов на; Основной цикл; Есть данные с; данных с ESP; Запись значения температуры в; Установка цвета i- го светодиода; Цикл установки цвета светодиодов; Цикл получения; Это HTTP запрос ?; HTTP запроса; Формирование HTTP; Получение данных; Отправка HTTP

Прерывание получения данных с АЦП

Вывод данных на светодиодную ленту

Обработка данных с ESP

Обработка HTTP запроса

Цикл получения данных
пока не достигнут
символ переноса строки

Цикл установки
цвета светодиодов
от 0 до значения
температуры

Вывод данных на
светодиодную
ленту

Отправка сформированных
данных на светодиодную

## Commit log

2023-10-02 Added E1
    [E1.dwg]
2023-10-06 Added E3
    [E1.dwg, E3.dwg]
2023-10-13 Added bill of materials and fixed E3
    [E3.dwg, ПЭ3.dwg]
2023-10-30 Restore changes
    [E3.dwg]
2023-12-10 Updated stamp and resistors
    [E1.dwg, E3.dwg, ПЭ3.dwg]
2023-12-10 Updated src
    [E1.dwg, E3.dwg, ПЭ3.dwg]
2023-12-10 Activated pcb raw drawing with src files
    [ПП.dwg]
2023-12-10 Fixed top
    [ПП.dwg]
2023-12-12 Added pcb drawing
2023-12-12 Fixed device name in pcb
    [E3.dwg, PCB.dwg, ПП.dwg]
2023-12-12 Added assembly of cell
    [Assembly.dwg]
2023-12-12 Fixed switch to new and renamed to bom
    [BOM.dwg, ПЭ3.dwg]
2023-12-12 Added ESP to assembly drawing
    [Assembly.dwg]
2023-12-12 Added specs for cell
    [Specs.dwg]
2023-12-12 Fixed e3
    [E3.dwg]
2023-12-13 Added E4
    [E4.dwg]
2023-12-13 Added research stand
    [E1.dwg, research_stand.dwg]
2023-12-13 Added research result
    [research_result.dwg]
2023-12-13 Updated names
    [Research Result.dwg, Research Stand.dwg]
2023-12-13 Added raw specs
    [Specs.dwg]
2023-12-14 Fixed name in cell specs
    [Specs.dwg]
2023-12-14 Added device specs
    [Specs.dwg]
2023-12-14 Added pcb sources
    [2AS1T2A1M6RES--3DModel-STEP-56544.STEP, CE3PRO_Top.3mf, ESP-01.STEP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]
2023-12-14 Added case sources
    [7243460688.ipt, 7243461008.iam, 7243461088.ipt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]
2023-12-14 Minor changes
    [Case-ASMB.iam, temperature-meter.PrjPcb]
2023-12-17 Added algorithm
    [Algorithm.dwg]
2023-12-17 Renamed case parts
    [Base.ipt, Cap.ipt]
2023-12-17 Added case base
    [Case Base.dwg]
2023-12-17 Added case base to todo
2023-12-17 Added case cap
    [Case Cap.dwg]
2023-12-17 Fixed device assembly
    [Case-ASMB.iam, PCB1.iam]
2023-12-17 Added device assembly drawing
    [Assembly.dwg]
2023-12-18 Fixed name in E4
    [E4.dwg]
2023-12-18 Fixed decimal number
    [Case Cap.dwg]
2023-12-20 Fixed resistors in E3
    [E3.dwg]
2023-12-20 Added sleeves models
    [Втулка_1.ipt, Втулка_2.ipt]
